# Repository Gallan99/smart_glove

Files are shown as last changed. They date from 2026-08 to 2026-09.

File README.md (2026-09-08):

# Smart Glove Strain Sensor System

A compact smart-glove project for measuring finger bending with five piezoresistive strain sensors. The system combines a custom constant-current analog front end, Arduino data acquisition and a simple Python interface for viewing and saving measurements.

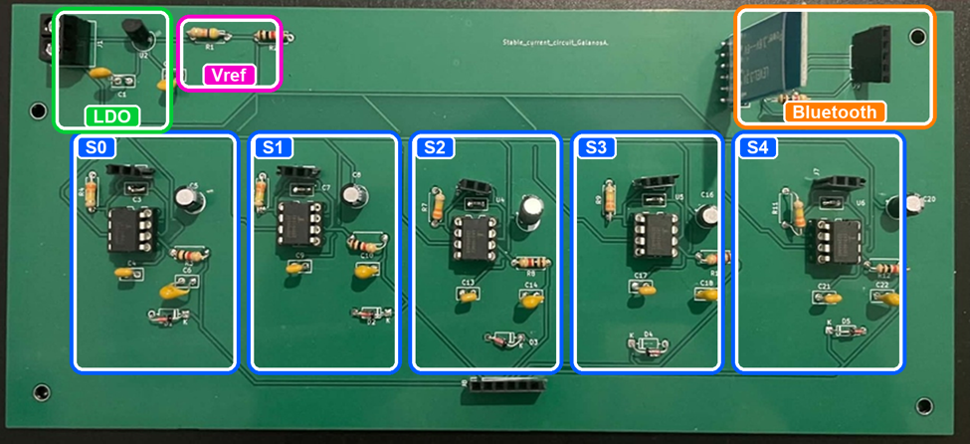
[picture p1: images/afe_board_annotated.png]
Five-channel sensor readout PCB


## Project overview

- Five strain-sensor channels connected to Arduino analog inputs A0-A4.
- Constant-current readout designed for sensors in the megaohm range.
- Resistance calculation, trimmed-mean sampling and IIR filtering on the Arduino.
- Serial data transmission at 115200 baud.
- Python desktop interface for live plotting and measurement logging.

## Files

| File | Description |
|---|---|
| [`stable_current_5sensors.ino`](stable_current_5sensors.ino) | Arduino firmware for reading and filtering five strain sensors. |
| [`gui_script_v2.py`](gui_script_v2.py) | Tkinter interface for serial measurements, live plotting and data logging. |
| [`kicad/`](kicad/) | KiCad project containing the schematic and PCB layout of the five-channel board. |
| [`images/`](images/) | Photos of the prototype and representative sensor measurements. |

## Hardware

The custom board contains five independent sensor-readout channels, a voltage reference, voltage regulation and Bluetooth connectivity.

Open [`kicad/test1.kicad_pro`](kicad/test1.kicad_pro) in KiCad to inspect the complete schematic and PCB design.

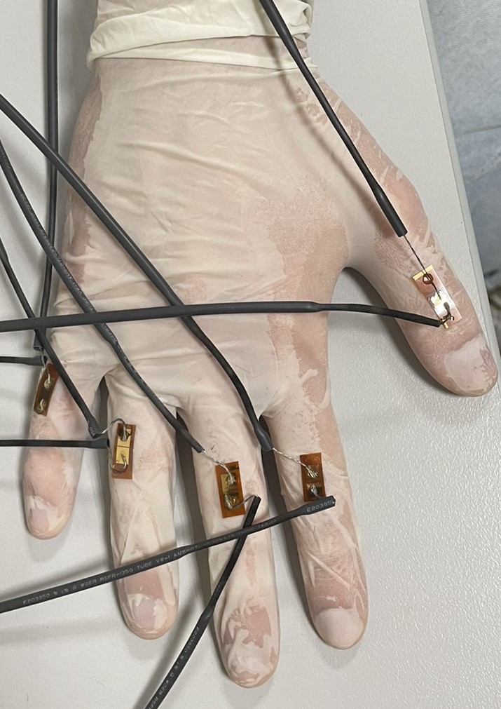
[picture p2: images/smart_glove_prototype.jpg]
Smart-glove prototype


## Sensor response

The sensors produce a clear resistance change as the fingers bend from 0° to 135°.

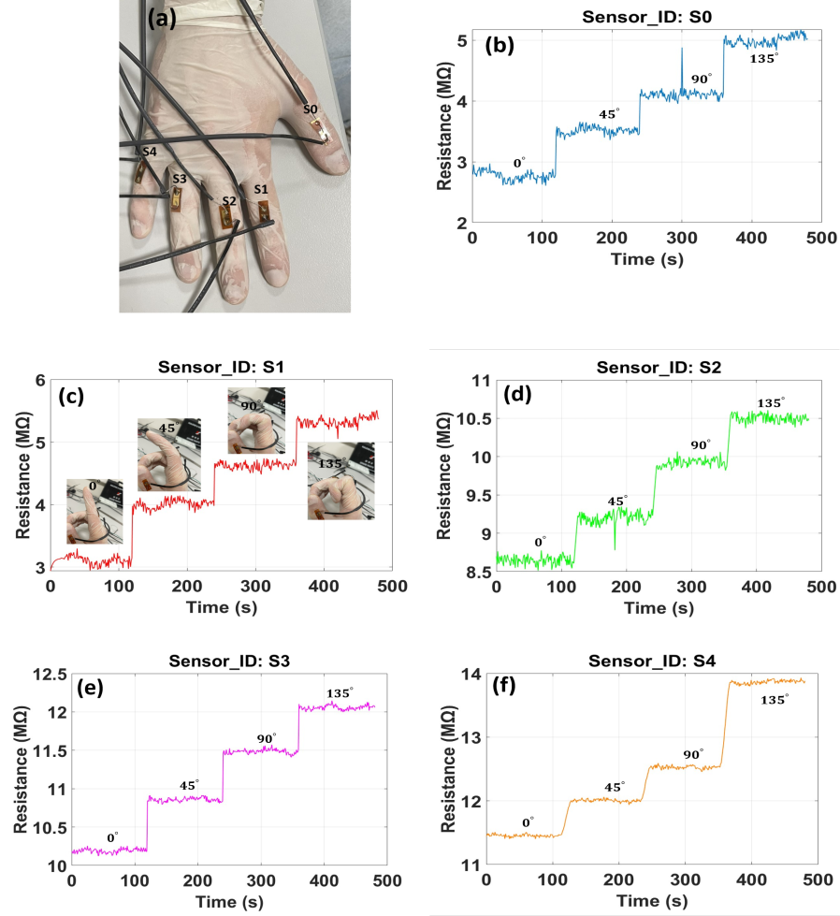
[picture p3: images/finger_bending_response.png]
Resistance response during finger bending


## Basic use

1. Open `stable_current_5sensors.ino` in the Arduino IDE.
2. Check the calibration constants `RSET_OHMS`, `VNODE_VOLTS` and `ADC_REF_VOLTS` for the specific board.
3. Upload the firmware to the Arduino and open the serial connection at 115200 baud.
4. Install the Python dependencies:

   ```bash
   pip install pyserial matplotlib
   ```

5. Start the desktop interface:

   ```bash
   python gui_script_v2.py
   ```

> **Note:** The Python interface is included in its original single-channel logging form. The Arduino file outputs five sensor channels, so the serial-field selection in the Python parser must be adapted when using the two files together.

## Related publication

The complete smart-glove system is described in the following preprint:

[A High-Fidelity Bluetooth-Enabled Smart Glove Using Platinum Nanoparticle-Based Strain Sensors and Machine Learning for Object Recognition](https://papers.ssrn.com/sol3/papers.cfm?abstract_id=7134952)

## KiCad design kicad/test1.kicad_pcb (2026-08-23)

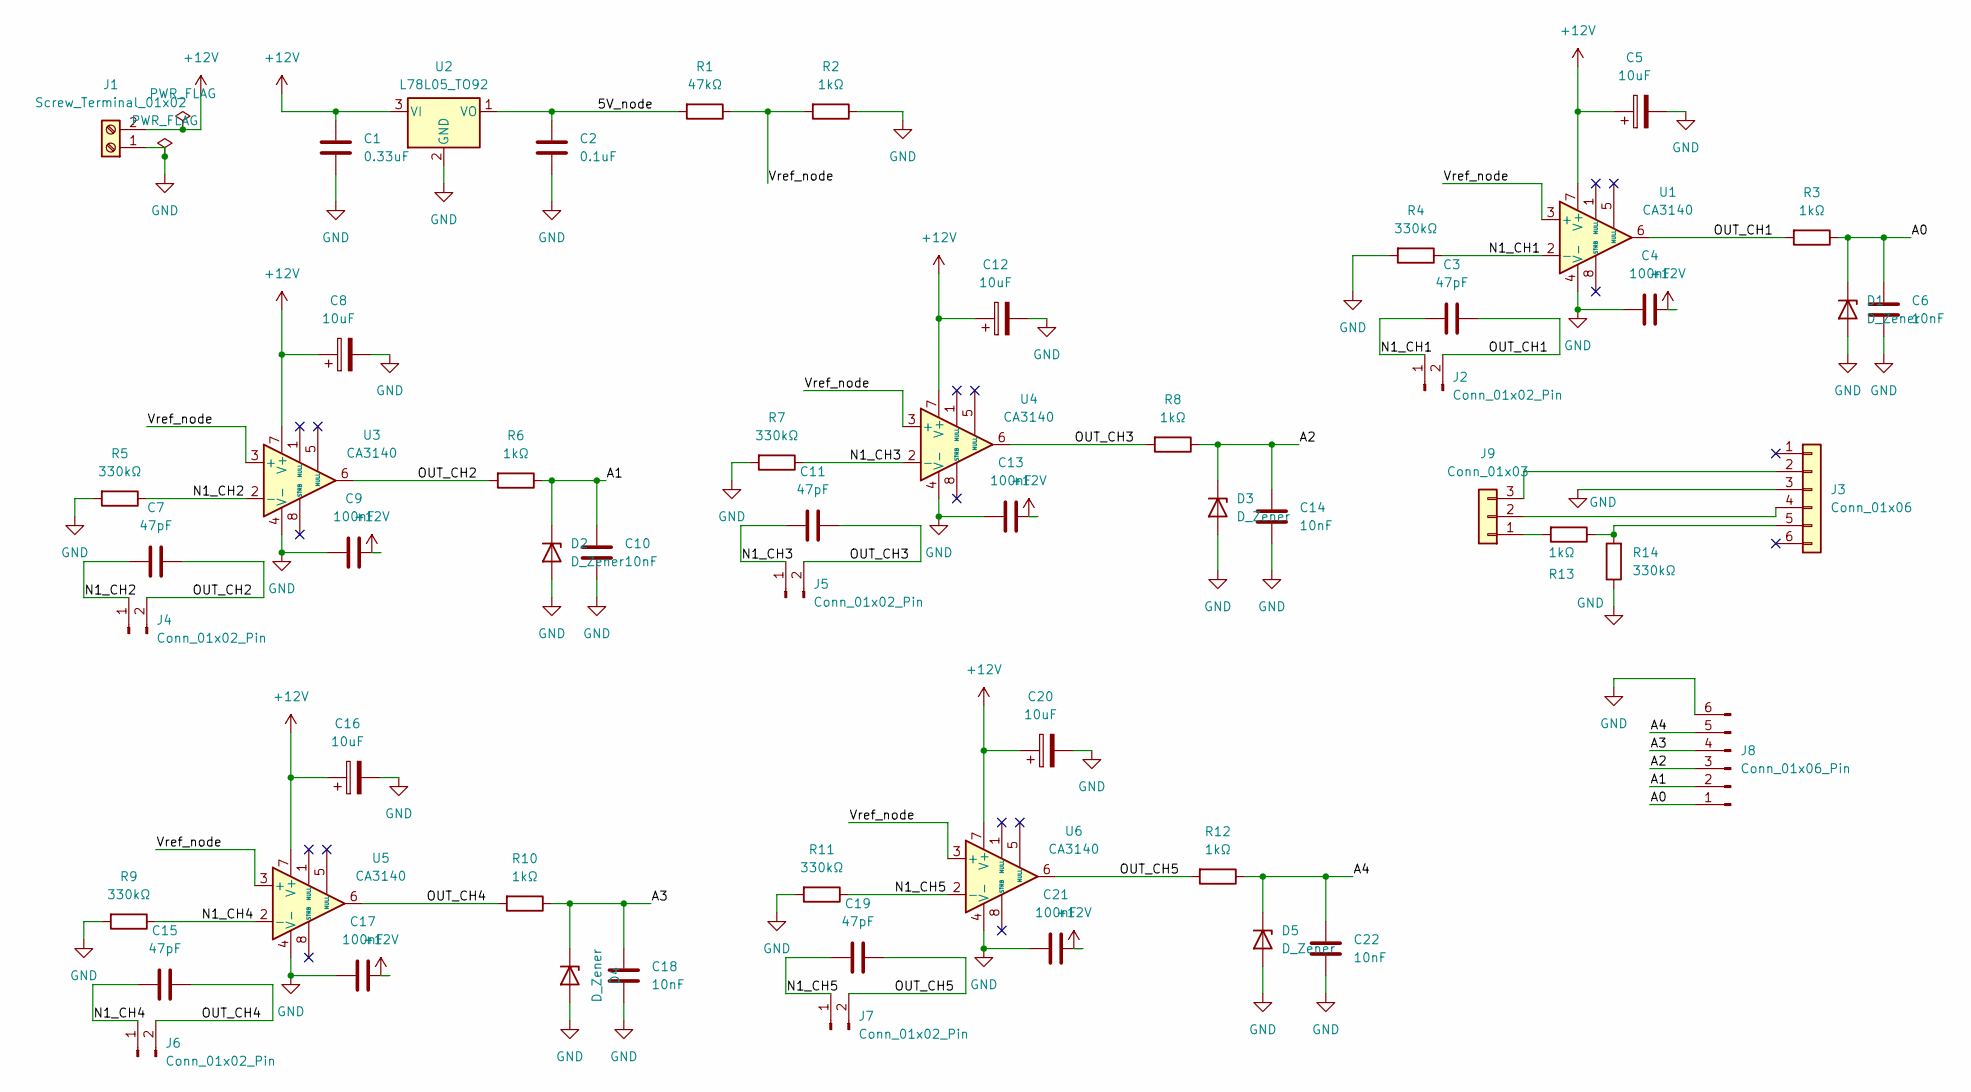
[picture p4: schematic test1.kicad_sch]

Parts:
C1: 0.33uF; C_Disc_D5.0mm_W2.5mm_P2.50mm
C2: 0.1uF; C_Disc_D5.0mm_W2.5mm_P2.50mm
C3, C7, C11, C15, C19: 47pF; C_Disc_D5.0mm_W2.5mm_P2.50mm
C4, C9, C13, C17, C21: 100nF; C_Disc_D5.0mm_W2.5mm_P2.50mm
C5, C8, C12, C16, C20: 10uF; CP_Radial_D5.0mm_P2.00mm
C6, C10, C14, C18, C22: 10nF; C_Disc_D5.0mm_W2.5mm_P2.50mm
D1, D2, D3, D4, D5: D_Zener; D_DO-35_SOD27_P7.62mm_Horizontal
J1: Screw_Terminal_01x02; TerminalBlock_Phoenix_MKDS-1,5-2-5.08_1x02_P5.08mm_Horizont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
J2, J4, J5, J6, J7: Conn_01x02_Pin; PinSocket_1x02_P2.54mm_Vertical
J3: Conn_01x06; PinSocket_1x06_P2.54mm_Vertical
J8: Conn_01x06_Pin; PinSocket_1x06_P2.54mm_Vertical
J9: Conn_01x03; PinSocket_1x03_P2.54mm_Vertical
R1: 47kΩ; R_Axial_DIN0207_L6.3mm_D2.5mm_P7.62mm_Horizontal
R2, R3, R6, R8, R10, R12, R13: 1kΩ; R_Axial_DIN0207_L6.3mm_D2.5mm_P7.62mm_Horizontal
R4, R5, R7, R9, R11, R14: 330kΩ; R_Axial_DIN0207_L6.3mm_D2.5mm_P7.62mm_Horizontal
U1, U3, U4, U5, U6: CA3140; DIP-8_W7.62mm_LongPads
U2: L78L05_TO92; TO-92_Inline

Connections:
+12V: C1.1, C4.1, C5.1, C8.1, C9.1, C12.1, C13.1, C16.1, C17.1, C20.1, C21.1, J1.2, U1.7 (V+), U2.3 (VI), U3.7 (V+), U4.7 (V+), U5.7 (V+), U6.7 (V+)
/5V_node: C2.1, R1.2, U2.1 (VO)
/A0: C6.2, D1.1 (K), J8.1, R3.1
/A1: C10.2, D2.1 (K), J8.2, R6.1
/A2: C14.2, D3.1 (K), J8.3, R8.1
/A3: C18.2, D4.1 (K), J8.4, R10.1
/A4: C22.2, D5.1 (K), J8.5, R12.1
/N1_CH1: C3.2, J2.1, R4.1, U1.2 (-)
/N1_CH2: C7.2, J4.1, R5.1, U3.2 (-)
/N1_CH3: C11.2, J5.1, R7.1, U4.2 (-)
/N1_CH4: C15.2, J6.1, R9.1, U5.2 (-)
/N1_CH5: C19.2, J7.1, R11.1, U6.2 (-)
/OUT_CH1: C3.1, J2.2, R3.2, U1.6
/OUT_CH2: C7.1, J4.2, R6.2, U3.6
/OUT_CH3: C11.1, J5.2, R8.2, U4.6
/OUT_CH4: C15.1, J6.2, R10.2, U5.6
/OUT_CH5: C19.1, J7.2, R12.2, U6.6
/Vref_node: R1.1, R2.2, U1.3 (+), U3.3 (+), U4.3 (+), U5.3 (+), U6.3 (+)
GND: C1.2, C2.2, C4.2, C5.2, C6.1, C8.2, C9.2, C10.1, C12.2, C13.2, C14.1, C16.2, C17.2, C18.1, C20.2, C21.2, C22.1, D1.2 (A), D2.2 (A), D3.2 (A), D4.2 (A), D5.2 (A), J1.1, J3.3, J8.6, R2.1, R4.2, R5.2, R7.2, R9.2, R11.2, R14.1, U1.4 (V-), U2.2 (GND), U3.4 (V-), U4.4 (V-), U5.4 (V-), U6.4 (V-)
unnamed: J3.2, J9.3
unnamed: J3.4, J9.2
unnamed: J3.5, R13.1, R14.2
unnamed: J9.1, R13.2

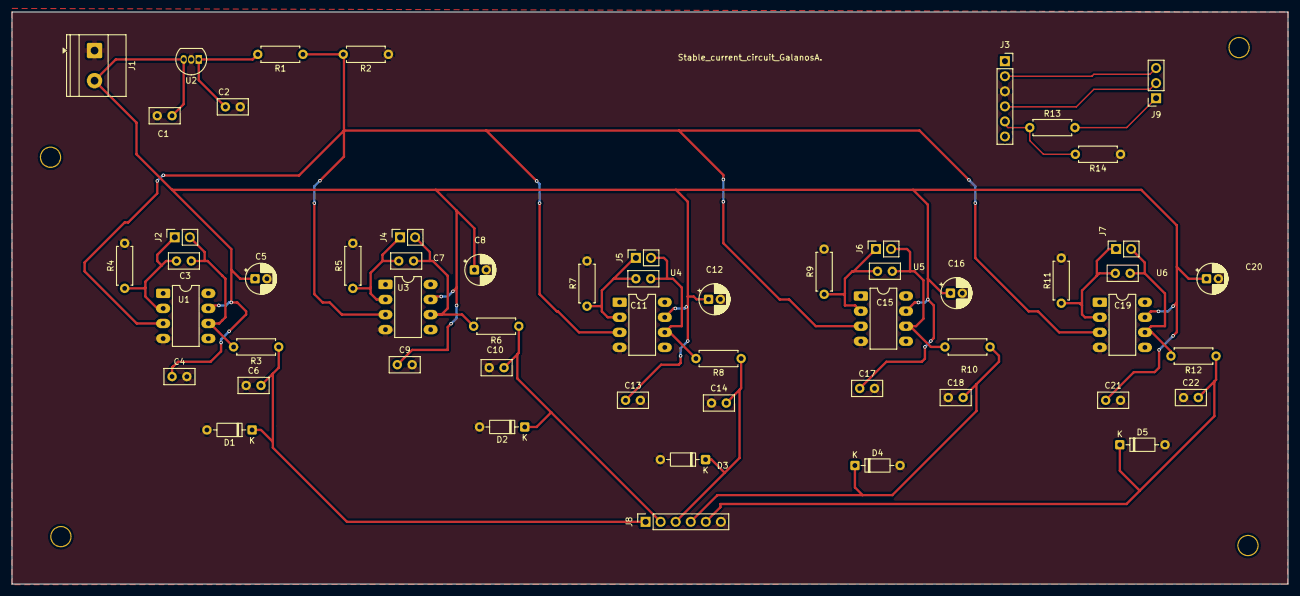
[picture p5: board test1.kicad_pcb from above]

Board: 2 copper layers, 215.2 x 96.5 mm, 56 parts (0 on the bottom side), 23 nets.

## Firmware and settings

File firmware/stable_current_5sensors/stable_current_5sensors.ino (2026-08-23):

#include <Arduino.h>

// =========================
// ΡΥΘΜΙΣΕΙΣ
// =========================

const uint8_t NUM_SENSORS = 5;
const uint8_t SENSOR_PINS[NUM_SENSORS] = {A0, A1, A2, A3, A4};

// ΠΡΑΓΜΑΤΙΚΕΣ ΜΕΤΡΗΣΕΙΣ ΑΝΑ ΚΑΝΑΛΙ
float RSET_OHMS[NUM_SENSORS] = {
  326900.0f, 325100.0f, 327600.0f, 335100.0f, 320500.0f
};

float VNODE_VOLTS[NUM_SENSORS] = {
  0.1044f, 0.1044f, 0.1044f, 0.1044f, 0.1044f
};

// Το πραγματικό 5V του Uno
const float ADC_REF_VOLTS = 4.970f;

// Ρυθμός εξόδου
// 50 ms = 20 Hz, matching the object-recognition acquisition protocol.
const uint32_t REPORT_INTERVAL_MS = 50;

// Samples ανά κανάλι σε κάθε περίοδο
const uint16_t SAMPLES_PER_CHANNEL = 12;

// Smoothing
const float IIR_ALPHA = 0.08f;

// =========================
// ΚΑΤΑΣΤΑΣΗ
// =========================

float rsFilteredOhm[NUM_SENSORS];
bool  rsFilterInit[NUM_SENSORS];

unsigned long t0_ms = 0;
unsigned long next_ms = 0;

// =========================
// ΒΟΗΘΗΤΙΚΑ
// =========================

float codeToVolts(float code) {
  return (code * ADC_REF_VOLTS) / 1023.0f;
}

void selectDefaultRef() {
  analogReference(DEFAULT);
  delay(2);
}

float readTrimmedMeanChannel(uint8_t pin, uint16_t samples) {
  // dummy read μετά από αλλαγή καναλιού
  analogRead(pin);
  delayMicroseconds(200);

  uint32_t sum = 0;
  int minVal = 1023;
  int maxVal = 0;

  for (uint16_t i = 0; i < samples; i++) {
    int v = analogRead(pin);

    sum += v;
    if (v < minVal) minVal = v;
    if (v > maxVal) maxVal = v;

    delayMicroseconds(200);
  }

  if (samples >= 4) {
    sum -= minVal;
    sum -= maxVal;
    return (float)sum / (float)(samples - 2);
  }

  return (float)sum / (float)samples;
}

void printHeader() {
  Serial.println(
    F("t_ms,"
      "adc0,Vout0_V,Rs0_MOhm,Rs0Filt_MOhm,status0,"
      "adc1,Vout1_V,Rs1_MOhm,Rs1Filt_MOhm,status1,"
      "adc2,Vout2_V,Rs2_MOhm,Rs2Filt_MOhm,status2,"
      "adc3,Vout3_V,Rs3_MOhm,Rs3Filt_MOhm,status3,"
      "adc4,Vout4_V,Rs4_MOhm,Rs4Filt_MOhm,status4")
  );
}

void setup() {
  Serial.begin(115200);

  selectDefaultRef();

  for (uint8_t i = 0; i < NUM_SENSORS; i++) {
    rsFilteredOhm[i] = NAN;
    rsFilterInit[i] = false;
  }

  // πέτα μερικές αρχικές μετρήσεις
  for (int k = 0; k < 10; k++) {
    for (uint8_t i = 0; i < NUM_SENSORS; i++) {
      analogRead(SENSOR_PINS[i]);
    }
    delay(5);
  }

  t0_ms = millis();
  next_ms = t0_ms + REPORT_INTERVAL_MS;

  printHeader();
}

void loop() {
  unsigned long now = millis();
  if ((long)(now - next_ms) < 0) {
    return;
  }

  float adcMean[NUM_SENSORS];
  float vOut[NUM_SENSORS];
  float iSetA[NUM_SENSORS];
  float rsOhm[NUM_SENSORS];
  float rsMOhm[NUM_SENSORS];
  float rsFiltMOhm[NUM_SENSORS];
  const char* status[NUM_SENSORS];

  selectDefaultRef();

  for (uint8_t i = 0; i < NUM_SENSORS; i++) {
    adcMean[i] = NAN;
    vOut[i] = NAN;
    iSetA[i] = NAN;
    rsOhm[i] = NAN;
    rsMOhm[i] = NAN;
    rsFiltMOhm[i] = NAN;
    status[i] = "OK";

    adcMean[i] = readTrimmedMeanChannel(SENSOR_PINS[i], SAMPLES_PER_CHANNEL);
    vOut[i] = codeToVolts(adcMean[i]);

    if (adcMean[i] < 2.0f) {
      status[i] = "WARN:NEAR_ZERO";
    } else if (adcMean[i] > 1020.0f) {
      status[i] = "WARN:NEAR_FS";
    }

    if (VNODE_VOLTS[i] <= 0.0f || RSET_OHMS[i] <= 0.0f) {
      status[i] = "ERROR:BAD_CFG";
      continue;
    }

    iSetA[i] = VNODE_VOLTS[i] / RSET_OHMS[i];

    if (vOut[i] <= VNODE_VOLTS[i]) {
      status[i] = "WARN:VOUT<=VREF";
      continue;
    }

    rsOhm[i] = (vOut[i] - VNODE_VOLTS[i]) / iSetA[i];
    rsMOhm[i] = rsOhm[i] / 1e6f;

    if (!rsFilterInit[i] || !isfinite(rsFilteredOhm[i])) {
      rsFilteredOhm[i] = rsOhm[i];
      rsFilterInit[i] = true;
    } else {
      rsFilteredOhm[i] =
        (1.0f - IIR_ALPHA) * rsFilteredOhm[i] + IIR_ALPHA * rsOhm[i];
    }

    rsFiltMOhm[i] = rsFilteredOhm[i] / 1e6f;
  }

  // Εκτύπωση CSV
  Serial.print(now - t0_ms);

  for (uint8_t i = 0; i < NUM_SENSORS; i++) {
    Serial.print(',');

    if (isnan(adcMean[i])) Serial.print(F("nan"));
    else Serial.print(adcMean[i], 2);
    Serial.print(',');

    if (isnan(vOut[i])) Serial.print(F("nan"));
    else Serial.print(vOut[i], 6);
    Serial.print(',');

    if (isnan(rsMOhm[i])) Serial.print(F("nan"));
    else Serial.print(rsMOhm[i], 6);
    Serial.print(',');

    if (isnan(rsFiltMOhm[i])) Serial.print(F("nan"));
    else Serial.print(rsFiltMOhm[i], 6);
    Serial.print(',');

    Serial.print(status[i]);
  }

  Serial.println();

  next_ms += REPORT_INTERVAL_MS;
  if ((long)(now - next_ms) >= 0) {
    next_ms = now + REPORT_INTERVAL_MS;
  }
}

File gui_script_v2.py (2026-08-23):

import tkinter as tk
from tkinter import ttk, messagebox, filedialog
import serial
import serial.tools.list_ports
import threading

# Εισαγωγές για το γράφημα και τα εργαλεία
import matplotlib.pyplot as plt
from matplotlib.backends.backend_tkagg import FigureCanvasTkAgg, NavigationToolbar2Tk
from matplotlib.ticker import FormatStrFormatter

class ArduinoLoggerGUI:
    def __init__(self, root):
        self.root = root
        self.root.title("Arduino Data Logger Pro")
        self.root.geometry("1000x750") 
        self.root.minsize(900, 650)

        # Μεταβλητές Κατάστασης
        self.serial_port = None
        self.is_logging = False
        self.log_thread = None
        self.file = None
        
        # Μοναδικός κωδικός για κάθε τρέξιμο (αποτρέπει τα "φαντάσματα")
        self.run_id = 0 

        # Δεδομένα Γραφήματος & Στατιστικών
        self.time_data = []
        self.rs_data = []
        self.all_rs_values = [] # Για τον υπολογισμό του μέσου όρου
        self.max_points = 100

        self.setup_ui()
        self.refresh_ports()

        self.root.protocol("WM_DELETE_WINDOW", self.on_closing)

    def setup_ui(self):
        # Κεντρικό Container
        main_frame = ttk.Frame(self.root, padding=10)
        main_frame.pack(fill="both", expand=True)

        # Αριστερή Στήλη (Ρυθμίσεις, Έλεγχος, Στατιστικά)
        left_column = ttk.Frame(main_frame, padding=5)
        left_column.pack(side="left", fill="y")

        # Δεξιά Στήλη (Γράφημα)
        right_column = ttk.Frame(main_frame, padding=5)
        right_column.pack(side="right", fill="both", expand=True)

        # --- 1. ΡΥΘΜΙΣΕΙΣ ΣΥΝΔΕΣΗΣ ---
        settings_frame = ttk.LabelFrame(left_column, text="Ρυθμίσεις Σύνδεσης", padding=10)
        settings_frame.pack(fill="x", pady=5)

        ttk.Label(settings_frame, text="Θύρα (COM):").grid(row=0, column=0, sticky="w")
        self.port_var = tk.StringVar()
        self.port_combo = ttk.Combobox(settings_frame, textvariable=self.port_var, state="readonly", width=12)
        self.port_combo.grid(row=0, column=1, padx=5, pady=5)
        ttk.Button(settings_frame, text="🔄", width=3, command=self.refresh_ports).grid(row=0, column=2)

        ttk.Label(settings_frame, text="Baud Rate:").grid(row=1, column=0, sticky="w")
        self.baud_var = tk.StringVar(value="115200")
        self.baud_combo = ttk.Combobox(settings_frame, textvariable=self.baud_var, state="readonly", width=12)
        self.baud_combo['values'] = ("9600", "115200", "250000")
        self.baud_combo.grid(row=1, column=1, padx=5, pady=5)

        ttk.Label(settings_frame, text="Αρχείο:").grid(row=2, column=0, sticky="w")
        self.file_var = tk.StringVar(value="data.txt")
        ttk.Entry(settings_frame, textvariable=self.file_var, width=15).grid(row=2, column=1, padx=5, pady=5)
        
        # --- ΝΕΟ: Κουμπί για περιήγηση στον υπολογιστή ---
        ttk.Button(settings_frame, text="📁", width=3, command=self.browse_file).grid(row=2, column=2)

        # --- 2. ΕΛΕΓΧΟΣ ---
        control_frame = ttk.Frame(left_column, padding=5)
        control_frame.pack(fill="x", pady=5)
        self.start_btn = ttk.Button(control_frame, text="▶ Έναρξη", command=self.start_logging)
        self.start_btn.pack(fill="x", pady=2)
        self.stop_btn = ttk.Button(control_frame, text="⏹ Διακοπή", command=self.stop_logging, state="disabled")
        self.stop_btn.pack(fill="x", pady=2)
        
        # --- Checkbox ---
        self.show_all_var = tk.BooleanVar(value=False)
        self.show_all_chk = ttk.Checkbutton(
            control_frame, 
            text="Προβολή όλου του ιστορικού", 
            variable=self.show_all_var,
            command=self.refresh_graph_view 
        )
        self.show_all_chk.pack(fill="x", pady=10)

        # --- 3. ΖΩΝΤΑΝΑ ΣΤΑΤΙΣΤΙΚΑ ---
        stats_frame = ttk.LabelFrame(left_column, text="Στατιστικά (MΩ)", padding=10)
        stats_frame.pack(fill="x", pady=5)

        self.max_val_var = tk.StringVar(value="0.000")
        self.min_val_var = tk.StringVar(value="0.000")
        self.avg_val_var = tk.StringVar(value="0.000")

        ttk.Label(stats_frame, text="Μέγιστο (Max):").grid(row=0, column=0, sticky="w")
        ttk.Label(stats_frame, textvariable=self.max_val_var, font=("Arial", 10, "bold")).grid(row=0, column=1, padx=10, sticky="e")

        ttk.Label(stats_frame, text="Ελάχιστο (Min):").grid(row=1, column=0, sticky="w")
        ttk.Label(stats_frame, textvariable=self.min_val_var, font=("Arial", 10, "bold")).grid(row=1, column=1, padx=10, sticky="e")

        ttk.Label(stats_frame, text="Μέσος Όρος:").grid(row=2, column=0, sticky="w")
        ttk.Label(stats_frame, textvariable=self.avg_val_var, font=("Arial", 10, "bold")).grid(row=2, column=1, padx=10, sticky="e")

        # --- 4. LIVE LOG ---
        log_frame = ttk.LabelFrame(left_column, text="Live Log", padding=5)
        log_frame.pack(fill="both", expand=True, pady=5)
        self.log_text = tk.Text(log_frame, width=30, height=10, state="disabled", font=("Consolas", 9))
        self.log_text.pack(fill="both", expand=True)

        # --- 5. ΓΡΑΦΗΜΑ & TOOLBAR (ΔΕΞΙΑ) ---
        self.fig, self.ax = plt.subplots(figsize=(7, 5), dpi=100)
        
        self.ax.set_title("Resistance vs Time", fontsize=14, fontweight='bold')
        self.ax.set_xlabel("Χρόνος (ms)")
        self.ax.set_ylabel("Rs Filtered (MΩ)")
        self.ax.yaxis.set_major_formatter(FormatStrFormatter('%.3f'))
        self.ax.grid(True, linestyle="--", alpha=0.6)
        
        self.line, = self.ax.plot([], [], color='#0078D7', marker='o', markersize=2, linewidth=1)
        
        self.canvas = FigureCanvasTkAgg(self.fig, master=right_column)
        self.canvas.draw()
        
        self.toolbar = NavigationToolbar2Tk(self.canvas, right_column)
        self.toolbar.update()
        self.canvas.get_tk_widget().pack(fill="both", expand=True)

    def refresh_ports(self):
        ports = [port.device for port in serial.tools.list_ports.comports()]
        self.port_combo['values'] = ports
        if ports: self.port_combo.current(0)

    # --- ΝΕΑ ΣΥΝΑΡΤΗΣΗ: Ανοίγει παράθυρο περιήγησης στον υπολογιστή ---
    def browse_file(self):
        filename = filedialog.asksaveasfilename(
            defaultextension=".txt",
            filetypes=[("Text Files", "*.txt"), ("CSV Files", "*.csv"), ("All Files", "*.*")],
            title="Επιλογή Αρχείου Αποθήκευσης"
        )
        # Αν ο χρήστης επιλέξει αρχείο (δεν πατήσει ακύρωση)
        if filename:
            self.file_var.set(filename)

    def update_stats(self, val, current_run_id):
        if current_run_id != self.run_id: return
        
        self.all_rs_values.append(val)
        mx = max(self.all_rs_values)
        mn = min(self.all_rs_values)
        av = sum(self.all_rs_values) / len(self.all_rs_values)
        
        self.max_val_var.set(f"{mx:.3f}")
        self.min_val_var.set(f"{mn:.3f}")
        self.avg_val_var.set(f"{av:.3f}")
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

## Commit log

2026-08-23 Initial release: five-channel smart glove platform
    [ball.csv, book.csv, bottle.csv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]
2026-08-23 Add complete five-channel smart glove platform
    [ball.csv, book.csv, bottle.csv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]
2026-09-08 Simplify repository to core strain sensor files
    [ball.csv, book.csv, bottle.csv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]
2026-09-08 Add KiCad schematic and PCB design
    [test1.kicad_pcb, test1.kicad_sch]
